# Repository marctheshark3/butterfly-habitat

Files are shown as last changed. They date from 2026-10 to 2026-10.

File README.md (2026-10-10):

# Butterfly habitat

A roughly 200 mm enclosure with a washable floor, drop-in walls, an external
sliding mesh door, and a removable mesh roof. PETG; indoor or sheltered use.

**Revision 0.11 is an engineering candidate.** Fabric thickness is provisionally
0.20 mm. Measure your compressed fabric before final release. Geometry and slicing checks pass with the documented wall supports. Physical fit,
mesh retention, and 50 door cycles remain untested. No support-free claim is made.

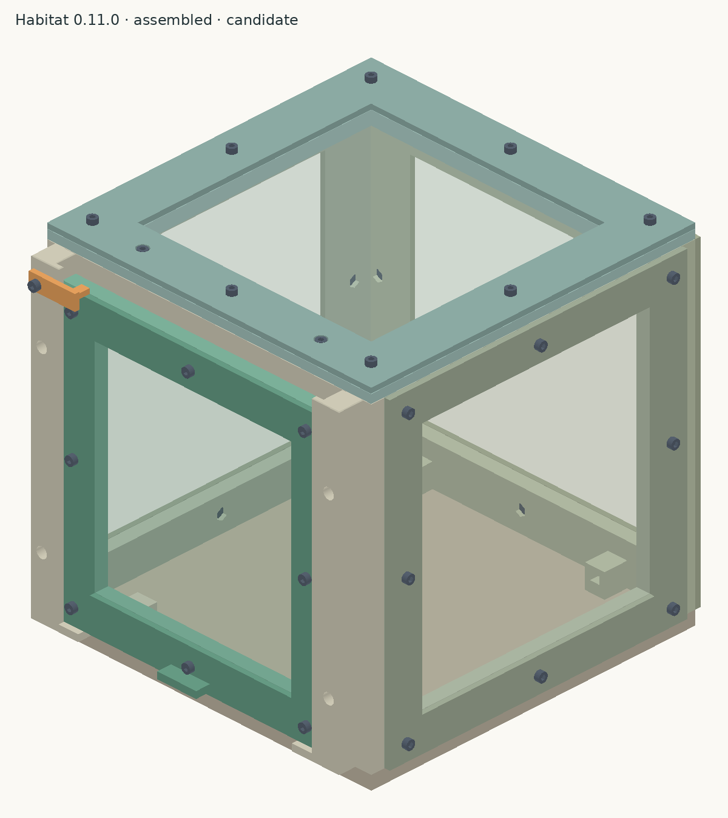
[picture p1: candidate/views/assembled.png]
Assembled habitat


## Start with a small mesh test

Print one of each in PETG:

1. [Mesh-fastener frame coupon](candidate/coupons/mesh-fastener-back.stl).
2. [Matching clamp coupon](candidate/coupons/mesh-fastener-back-clamp.stl).

Import them as **separate objects** in Bambu Studio and keep their supplied
orientations. Test with your actual mesh, M3 × 10 socket-head screws and M3
nyloc nuts. Check nut fit, full engagement through the nylon locking section,
recessed screw tips and firm fabric retention without cracking the clamp.

If that passes, print the [door](candidate/stl/habitat-door.stl) and
[door clamp](candidate/stl/habitat-door-clamp.stl). This tests a complete mesh
border using eight screws and eight nuts, and can become the finished door.
Then test the [rail and corner coupons](candidate/coupons/) before printing the
large panels. The full door-cycle test also needs the front frame, both rails
and keeper. The mesh-fastener coupon prints were reported successful. Mesh was not yet
available for the test; fabric retention, assembled thickness and full hardware
engagement remain unverified.

## P1S print setup

| Setting | Candidate configuration |
| --- | --- |
| Printer / nozzle | Bambu Lab P1S / 0.4 mm |
| Material | PETG; current slices use Generic PETG |
| Build plate | Textured PEI |
| Layer height | 0.20 mm |
| Walls / infill | 4 walls / 20% |
| Brim | 5 mm outer brim |
| Supports | Build-plate-only normal supports on front, back, left and right |
| Orientation | Already applied to STLs; keep it when importing |

Match the slicer’s filament and plate selections to what is actually installed.
The 15 production parts need multiple plates. The existing
[sliced projects](candidate/slicing/) document the candidate settings; inspect
your arranged plate and slice preview before sending a job to the printer.
See the [print specification](docs/PRINT_SPEC.yaml) for part-by-part orientation.

## Color plan

The local inspector previews four filament colors. Screen colors are approximate.

| Color | Parts |
| --- | --- |
| Medium blue | Base, front, back, left, right, roof |
| Matte pink | Back/side/roof clamps and both rails |
| Orange | Door and door clamp |
| Red | Rotating keeper / latch |

These are separate printed parts, so the scheme does not require color changes
within a part. The static reference images below retain the earlier neutral
palette. The inspector palette is defined in `inspector/colors.json`.

The manufacturing baseline remains PETG. If using matte PLA instead, select
its matching filament profile and repeat the fit tests with that material.

### PLA prints while waiting for mesh

The builder selected PLA for the current spools. The
[PLA starter pack](candidate/print-first/README.md) contains prepared P1S projects
for the blue corner-fit coupons, then the actual blue base, blue front and red
keeper. Start with the corner fit; the base is the first full-size print.
These use Generic PLA until a spool-specific profile is selected. The original
`candidate/slicing/` projects remain PETG. Mesh-dependent parts and physical
release checks remain pending.

## Selected mesh candidate

[uxcell 150-micron nylon mesh, 39 × 39 inches](https://www.amazon.com/dp/B09VC3K6C2)
is the selected candidate. One sheet is sufficient for the five panel cutouts.
The 150-micron rating describes the openings, **not the fabric thickness**.
Measure its compressed thickness and test retention with the coupons before
finalizing the mesh-dependent parts. No measured thickness or mesh-fit result
has been recorded yet. The current CAD still assumes 0.20 mm.

For use with monarch eggs and hatchlings, fine mesh alone is insufficient:
door and wall gaps also need checking before the enclosure is used.

## Assembly at a glance

### Built-in part IDs for future prints

The separate [labeled print set](candidate/labeled/README.md) has recessed IDs modeled
into all 15 parts. The existing Bambu projects and unmarked candidate files
remain the current build's print set. There is no need to reprint existing
pieces just for a label; use the [ID key](docs/ASSEMBLY.md#part-id-key) and
[paper labels](candidate/templates/part-labels.svg) to identify them.

| Assembly | IDs |
| --- | --- |
| Base | A1 |
| Front, left rail, right rail, keeper | B1, B2, B3, B4 |
| Back frame and clamp | C1 + C2 |
| Left frame and clamp | D1 + D2 |
| Right frame and clamp | E1 + E2 |
| Door frame and clamp | F1 + F2 |
| Roof frame and clamp | G1 + G2 |

Letters identify assemblies; matching frame/clamp pairs use `1` and `2`.
Left and right are viewed from outside the front doorway. The written guide,
inspector booklet and paper labels use the same IDs.

The marks are 0.4 mm deep with 0.8 mm strokes. Their locations retain at least
1.6 mm of backing and keep the original envelopes and print orientations.
CAD checks cover the labeled solids and interfaces; physical label legibility
and fit remain untested. The [variant manifest](candidate/labeled/assembly/manifest.json)
records each label location and both source hashes. This is still the 0.11.0
engineering candidate, with the same unmeasured mesh assumption.

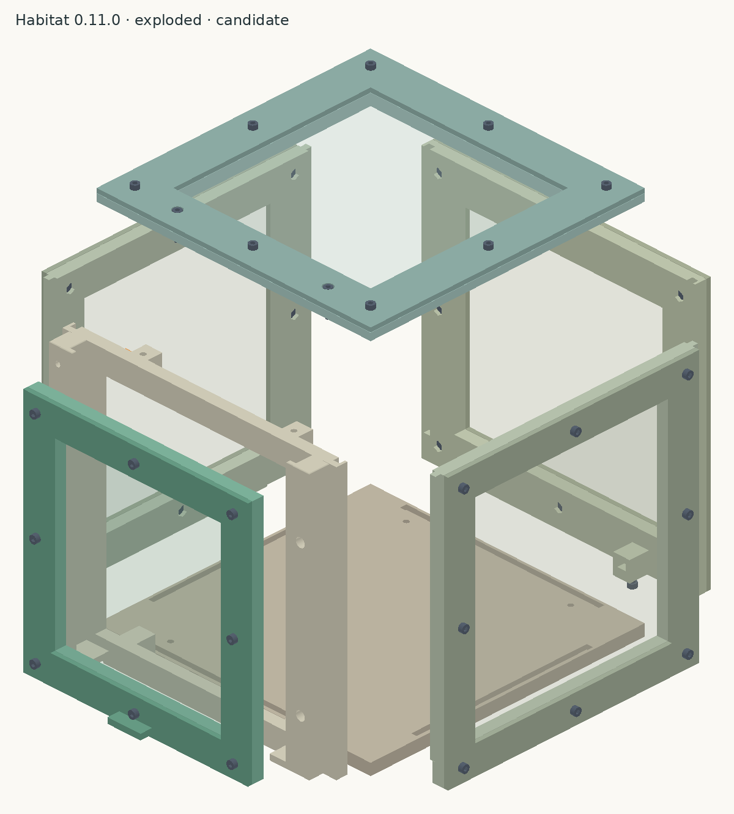
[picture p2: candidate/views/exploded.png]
Exploded CAD reference showing the habitat parts


*Exploded reference view. Offsets show the parts; they are not installation paths.*

1. Clamp mesh to the back, left, right, door and roof frames on the bench.
2. Preload the remaining nuts in the front, back and left rail.
3. Attach the two rails and rotating keeper to the front frame.
4. Seat front and back in the base; secure with four screws from underneath.
5. Lower the side panels into the open wall joints and base grooves.
6. Slide the door down the outside tracks and check the keeper.
7. Seat the roof and install its two separate retention screws from above.
8. Check the fabric, hardware and joints; complete 50 door cycles.

The [illustrated assembly guide](docs/ASSEMBLY.md) gives the hardware counts,
nut directions and checks for each step. Cut mesh using the
[1:1 templates](candidate/templates/) and identify parts with the
[paper labels](candidate/templates/part-labels.svg).

| Hardware | Quantity |
| --- | ---: |
| Stainless M3 × 10 socket-head screw | 45 |
| Stainless M3 × 16 socket-head screw | 6 |
| M3 nyloc nut, 5.5 mm flats × 4 mm overall height | 51 |

Use a 2.5 mm hex driver. The five mesh rings each use eight short screws.
The remaining five short screws attach the rails and keeper. Four long screws
retain the base and two retain the roof. See the [hardware list](candidate/hardware.csv).

### Door and roof access

| Door lifts out with the roof installed | Roof lifts off as one assembly |
| --- | --- |
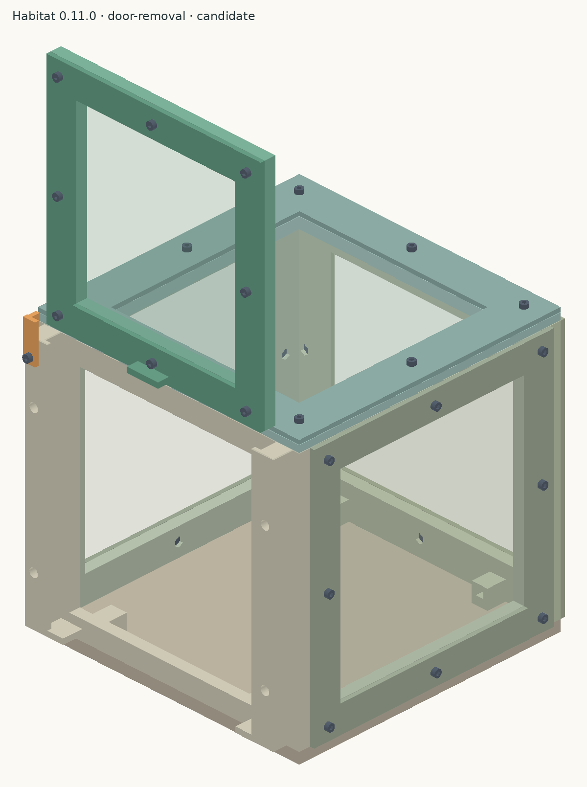
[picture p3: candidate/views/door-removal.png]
Door removal CAD view
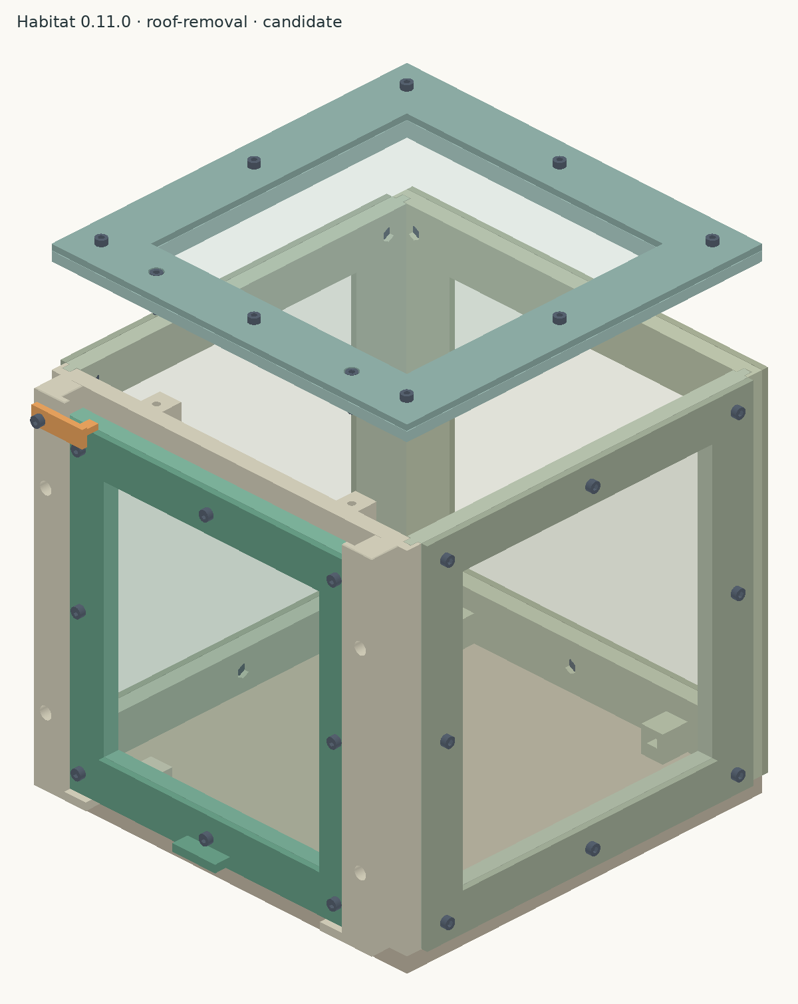
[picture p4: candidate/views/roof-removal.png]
Roof removal CAD view
|  |  |

Swing the keeper clear before lifting the door; allow about 190 mm upward
travel. Remove only the roof’s **two long retention screws** to lift it off.
Its eight mesh screws stay assembled. Keep the walls upright while the roof is off.

## Files

- [Candidate STLs](candidate/stl/) — 15 printed parts, one of each file.
- [STEP parts](candidate/step/) and [complete assembly](candidate/assembly/habitat-assembly.step).
- [Assembly guide](docs/ASSEMBLY.md), [hardware list](candidate/hardware.csv), and [mesh templates](candidate/templates/).
- [Fit coupons](candidate/coupons/) — start here before a complete panel or habitat.
- [Print specification](docs/PRINT_SPEC.yaml) and [validation evidence](candidate/validation.json).
- [Sliced projects](candidate/slicing/) — inspection evidence; review before printing.

Old STLs, snap coupons, source and tests are under `archive/`. Do not mix
revisions. Historical planning notes and camera sketches describe earlier work.

## Local CAD inspector

From the repository root:

```sh
python3 -m http.server 8118 --bind 127.0.0.1 --directory inspector
```

Open [localhost:8118](http://127.0.0.1:8118/). The inspector contains all
122 components: 15 prints, five mesh sheets, 51 screws and 51 nuts.
Drag to orbit, scroll to zoom, click parts to inspect, or use the translucent,
exploded and section views.

The **Instructions** button generates a printable 12-step booklet inside the
inspector, with CAD illustrations, hardware counts and assembly directions.
It shows the five mesh subassemblies separately before the enclosure steps.
The header also links to the written guide.

To refresh the viewer after changing CAD, export its model with FreeCAD and
regenerate the instructions:

```sh
APPIMAGE_EXTRACT_AND_RUN=1 VibeCADCmd scripts/label-parts.py
APPIMAGE_EXTRACT_AND_RUN=1 VibeCADCmd scripts/export-inspector.py
python3 scripts/labels.py
python3 scripts/assembly-guide.py
```

Edit `scripts/assembly-guide.py` to update the shared sequence used by the
Markdown guide, browser guide and inspector booklet.
Edit `src/part_ids.py` for the shared ID map and engraving locations. The label
exporter writes `candidate/labeled/` and does not replace the original print
set. Re-slice the labeled geometry before printing; existing unmarked G-code
cannot acquire labels from a guide update.

## Build and check

The generator needs FreeCAD's Python modules (`FreeCAD`, `Part`, `MeshPart`).
On this workstation VibeCADCmd provides them. It does not set `__main__` when
loading a script, so use the entry point:

```sh
APPIMAGE_EXTRACT_AND_RUN=1 VibeCADCmd scripts/cad-entry.py
APPIMAGE_EXTRACT_AND_RUN=1 HABITAT_ACTION=export VibeCADCmd scripts/cad-entry.py
```

The first command checks in memory. It cannot overwrite STL or STEP files.
The second checks and exports the complete candidate set, manifest, hardware
list, cutting templates, coupons and inspection views. Direct module imports
also have no export side effects. The entry point returns nonzero on validation
failure. Require `geometry_pass: true` and a fresh manifest matching the source hash.

Set `HABITAT_MESH_MM` to your measured compressed thickness and
`HABITAT_MESH_MEASURED=1` only after measuring it. The supported stack range is
0.05–0.40 mm. A thicker material requires a fastening redesign.

```sh
python3 scripts/slice.py --profiles /path/to/BambuStudio/resources/profiles/BBL
python3 scripts/labels.py
python3 -m unittest discover -s tests
# Optional PNG inspection views; needs numpy and Pillow:
python3 scripts/render-views.py
```

To re-slice one part, add `--part habitat-base`. The results for the other parts
are retained. New slices run in a clean temporary directory, so an old project
cannot be mistaken for a successful new slice. Source, profile and project
hashes are recorded with each new result.

For PLA, choose a separate output directory to keep the PETG evidence intact:

```sh
python3 scripts/slice.py --profiles /path/to/BambuStudio/resources/profiles/BBL \
  --filament 'Generic PLA' --output candidate/slicing-pla --part habitat-base
```

An output directory cannot mix different printer/process/filament profiles.
Use a fresh directory when changing those settings. Keep the starter projects'
color assignments when preparing new PLA plates.

## Repository checks

These checks use Python 3.10+ and do not require FreeCAD, Bambu Studio or a
printer. The installer downloads a checksum-pinned Gitleaks release into the
ignored `.local/bin/` directory on Linux or macOS:

```sh
python3 scripts/install-gitleaks.py
python3 -m unittest discover -s tests -v
python3 scripts/package-starter.py --check
python3 scripts/check-secrets.py --history
```

The [GitHub Actions workflow](.github/workflows/checks.yml) runs the same checks
on pushes and pull requests with read-only permissions. It checks exported CAD
evidence and meshes, slicer failure handling, PLA project settings, source
hashes, ZIP contents, and secret detection inside current, staged and historical
print archives. It does not substitute for FreeCAD regeneration or physical
fit tests. Secret handling rules are in [AGENTS.md](AGENTS.md).

To rebuild the PLA download ZIP after an approved project or guide update, run
`python3 scripts/package-starter.py`. It validates the projects first and creates
a repeatable archive containing only the listed files. `--check` verifies the
existing ZIP and loose STL copies without modifying them.

## Validation status

Geometry checks cover all 7,381 assembly pairs, fastener alignment, intended
contacts, door/roof motion and installation access. The 15 production parts
have sliced successfully using the documented P1S PETG settings.

Fabric thickness is still an **unmeasured 0.20 mm assumption**. Coupon fit,
full-panel mesh retention and the 50-cycle door test remain pending. This is
an engineering candidate, not a fit-verified release.
[Verification and release](docs/VERIFICATION.md) describes the checks,
limitations and evidence needed for release.

MIT. See [LICENSE](LICENSE).

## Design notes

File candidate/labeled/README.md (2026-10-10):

# Labeled parts for future prints

Separate engraved-ID variant of the 0.11.0 engineering candidate. The original unmarked STL files, starter pack and current Bambu project are unchanged. Existing parts do not need reprinting for identification.

Each model has a 0.4 mm recessed ID with 0.8 mm strokes. All print orientations and outer dimensions are preserved. Matching frame/clamp pairs share a letter. Left and right are viewed from outside the front doorway.

[Assembly instructions and ID key](../../docs/ASSEMBLY.md#part-id-key) · [Actual STL label close-ups](label-details.png) · [Paper labels](templates/part-labels.svg)

The prepared projects use **Bambu PLA Matte**, a P1S with a 0.4 mm nozzle, Textured PEI, 0.20 mm layers, four walls, 20% infill and a 5 mm outer brim. Front/back/left/right frames have normal build-plate supports. Load the matching color before printing.

| ID | Part | Color | Model | Prepared project |
| --- | --- | --- | --- | --- |
| A1 | base | Blue | [STL](stl/habitat-base.stl) | [Bambu 3MF](slicing-PLA-Matte/habitat-base/sliced.3mf) |
| B1 | front frame | Blue | [STL](stl/habitat-front.stl) | [Bambu 3MF](slicing-PLA-Matte/habitat-front/sliced.3mf) |
| B2 | left rail | Pink | [STL](stl/habitat-rail-left.stl) | [Bambu 3MF](slicing-PLA-Matte/habitat-rail-left/sliced.3mf) |
| B3 | right rail | Pink | [STL](stl/habitat-rail-right.stl) | [Bambu 3MF](slicing-PLA-Matte/habitat-rail-right/sliced.3mf) |
| B4 | keeper / latch | Red | [STL](stl/habitat-keeper.stl) | [Bambu 3MF](slicing-PLA-Matte/habitat-keeper/sliced.3mf) |
| C1 | back frame | Blue | [STL](stl/habitat-back.stl) | [Bambu 3MF](slicing-PLA-Matte/habitat-back/sliced.3mf) |
| C2 | back clamp | Pink | [STL](stl/habitat-back-clamp.stl) | [Bambu 3MF](slicing-PLA-Matte/habitat-back-clamp/sliced.3mf) |
| D1 | left frame | Blue | [STL](stl/habitat-left.stl) | [Bambu 3MF](slicing-PLA-Matte/habitat-left/sliced.3mf) |
| D2 | left clamp | Pink | [STL](stl/habitat-left-clamp.stl) | [Bambu 3MF](slicing-PLA-Matte/habitat-left-clamp/sliced.3mf) |
| E1 | right frame | Blue | [STL](stl/habitat-right.stl) | [Bambu 3MF](slicing-PLA-Matte/habitat-right/sliced.3mf) |
| E2 | right clamp | Pink | [STL](stl/habitat-right-clamp.stl) | [Bambu 3MF](slicing-PLA-Matte/habitat-right-clamp/sliced.3mf) |
| F1 | door frame | Orange | [STL](stl/habitat-door.stl) | [Bambu 3MF](slicing-PLA-Matte/habitat-door/sliced.3mf) |
| F2 | door clamp | Orange | [STL](stl/habitat-door-clamp.stl) | [Bambu 3MF](slicing-PLA-Matte/habitat-door-clamp/sliced.3mf) |
| G1 | roof frame | Blue | [STL](stl/habitat-roof.stl) | [Bambu 3MF](slicing-PLA-Matte/habitat-roof/sliced.3mf) |
| G2 | roof clamp | Pink | [STL](stl/habitat-roof-clamp.stl) | [Bambu 3MF](slicing-PLA-Matte/habitat-roof-clamp/sliced.3mf) |

CAD and slice checks are recorded in [validation.json](validation.json), [the source manifest](assembly/manifest.json) and [slice results](slicing-PLA-Matte/results.json). Motion uses the original, larger part envelopes; the engravings only remove material. Physical fit and printed label legibility remain unverified. Compressed mesh thickness is still the unmeasured 0.20 mm assumption.

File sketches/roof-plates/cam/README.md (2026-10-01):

## Variant: camera roof

### Design stance
The corner is a pod sized to the board. The lens hole stays undrawn until a center exists.

### Key choices
- Pod outer 25.8 by 22.6 mm from the datasheet envelope, 0.4 mm clearance per side, 2.0 mm wall. Clearance and wall are assumed.
- USB slot leaves through the side, not the top.
- Mesh seals to the pod wall.
- Look-down is the sentence already in PRINT_SPEC. It is not a measured aim.

### Trade-offs
- Strong at: replacing the shelf with a real bay, and refusing a fake lens.
- Weak at: cannot be milled until `cam_lens_dx_mm` and `cam_lens_dy_mm` are recorded.

### Best for
A later plate, printed only after the board is measured.

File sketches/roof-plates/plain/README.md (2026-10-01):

## Variant: plain roof

### Design stance
The photo corner is a bug, so the plate is a full mesh frame and nothing else.

### Key choices
- Layout: 200 mm square, 12 mm border, 176 mm window, clamp is a closed ring.
- The 48 by 40 mm shelf and the 8 mm hole are gone.
- Roof still lifts off. That is the hatch.

### Trade-offs
- Strong at: closing the corner, giving the caterpillars mesh there, matching a no-camera build.
- Weak at: no place to put the XIAO without a new plate.

### Best for
The build in hand if the camera stays off.

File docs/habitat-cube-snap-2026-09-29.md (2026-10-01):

> Historical reference. Superseded for printing and assembly by [revision 0.11](../README.md).

# Cube snap coupon

Mesh screws stay mesh screws. The snap coupon is parked. Do not print another pair. Both printed pairs opened a gap after the click. The tighter one was only harder to start.

The drop-in is now in the cube CAD. Spec 0.9.0. Four screws, front and back, into solid corner pads. Not a print. Not fit-tested.

The 0.30 pair was tougher to start and still wiggled. The 0.40 pair started easier and wiggled the same way. Side clearance was not the wiggle. The hook was sitting 3 mm past the lip, so the plates could pull apart that far after they clicked.

- `stl/habitat-snap-tongue-coupon.stl`
- `stl/habitat-snap-pocket-coupon.stl`

The plates are 8 mm, not 6. A 6 mm plate cannot keep a 1.6 mm floor, a 0.8 mm hook, and a 1.6 mm roof. The wall gate failed the 6 mm pocket at a 1.25 mm floor. Do not copy this stack onto a 6 mm frame. The cube mill, later, thickens the pocket locally or turns the hook into the border plane.

Push the tongue into the open end of the pocket. Latched, the tongue is straight. The hook sits in the relief. The lip blocks a straight pull.

## If the click is wrong

Two numbers changed because the last reprint proved the side gap was the wrong knob. Do not reprint the cube.

- Still opens a gap once in: `snap_pocket_depth_mm` to 0.3. Do not tighten the side gap.
- Arm stays bent when the plates are together: `snap_pocket_depth_mm` to 0.8. Do not deepen the hook.
- Will not start: `snap_clearance_per_side_mm` to 0.45. One change.
- Straight pull opens it: `snap_return_angle_deg` to 60.
- Thumb cannot open it: `snap_return_angle_deg` to 40. Do not go to 90.
- Crack at the root after ten cycles: the tongue was printed in the orientation that worked. Do not thicken it on the first crack.

## Screws, later

Not this reprint. The eight M3 holes stay the mesh pinch. They do not join the cube. The four base holes inset 10 mm come out into air. Do not use them.

When the rattle is gone, the cube gets 4 screws, one at each bottom corner, wall into base. The roof stays snaps only, so it still lifts off. If a vertical seam still rattles, 4 more, one mid-height per corner. Ceiling is 8 cube screws. Not eight per frame.

Source stays `assumed` until that rattle is gone. `fit.required` stays false. That block is the door's 2 mm slop.

## Leave alone

Plate A. Door lips. Drain slots. The eight M3 pinch holes. Side length. Lens hole.

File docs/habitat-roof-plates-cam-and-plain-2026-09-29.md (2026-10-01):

> Historical reference. Superseded for printing and assembly by [revision 0.11](../README.md).

# Habitat roof plates, plain and camera, 2026-09-29

Point a session at this file for the roof only. The hinge and the floor slits are a different brief.

[This roof-plate brief](habitat-roof-plates-cam-and-plain-2026-09-29.md)

Sibling, do not merge them into one cut:

[Front hinge and floor brief](habitat-front-hinge-floor-slits-2026-09-29.md)

Drawing, both plates:

[Roof-plate drawing](../sketches/roof-plates/index.html)

For the current local inspector, see the [README](../README.md#local-cad-inspector).

Not a print approval. Pick is Plate A. The live roof is the full mesh frame. Do not send it to the printer from this brief.

## What the photo was

The near corner of the roof was a 48 by 40 mm shelf, 4 mm tall, on the 6 mm plate. An 8 mm hole sat in that shelf. The blue clamp was cut away around it. The tan sheet stopped short of it. That was `build_top` and `build_clamp_roof`. Plate A removes it.

That hole was `cable_hole_diameter_mm`, 8.0, source assumed. It was not a lens. The official DXF has no lens circle. `cam_offsets_ready` stays false. `docs/XIAO_SENSE_DATUM.md` is the record.

The spec used to say the pod is a roof-corner pocket and the lens looks down. Plate A retires that sentence. Plate B stays a drawing until a lens center exists.

## Plate A, no camera

Full 200 mm frame. Border 12 mm. Window 176 by 176 mm. Clamp is a full ring, not a notch. Mesh covers the photo corner. No shelf. No 8 mm hole. Roof still lifts off. That lift is still the hatch.

This is the fix for the shot. It also gives the caterpillars mesh in that corner.

Screw dots on the drawing are M3 clearance, 3.6 mm. They are not a joint into the walls. Do not treat the sketch pattern as a fastener.

## Plate B, camera

Same cube. One corner becomes a pod sized to the board, not a 48 by 40 shelf.

- Board 21.0 by 17.8 by 15.0 mm. Datasheet. Already in the spec.
- Clearance 0.4 mm per side. Assumed. Pocket 21.8 by 18.6 mm.
- Wall 2.0 mm. Assumed. Above the 1.6 mm minimum wall.
- Pod outer 25.8 by 22.6 mm. It eats the 12 mm border and a bite of the window.
- USB slot 9.0 by 3.5 mm on the short edge, out the side face of the cube. Not a hole in the top.
- Mesh seals to the pod wall. No open step like the photo.
- Lens looks down. That is the existing spec sentence, not a measured aim.
- Lens hole is not drawn. Center is unknown. Do not cut a 6 mm aperture until a caliper or a marked board supplies `cam_lens_dx_mm` and `cam_lens_dy_mm`.

The red dash on the drawing is a warning, not a hole.

## Decision

Write one line here before any roof cut.

Pick: Plate A. Camera stays off. The 48 by 40 shelf is not an option.

- Recommend if the cam stays off. Plate A.
- Plate B only after a lens center exists. Until then Plate B is a drawing.
- Do not keep the 48 by 40 shelf as a third option. That is the bug.

## Leave alone in this cut

Front hinge. Floor slots. Side length. A printed grille. A lens hole with no datum.

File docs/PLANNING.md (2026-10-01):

> Historical reference. Superseded for printing and assembly by [revision 0.11](../README.md).

# Planning notes

For the next session. Not a print approval. Camera pod stays off.

## What is true now

The cube is a stack of plates. The front butts the floor, the two sides, and the roof. It does not snap, and nothing screws it on. The four holes in the front corners exit into empty air. The floor corner holes miss the walls the same way.

The door drops into three lips and lifts out the open top. Its screws match the door clamp only. They pinch a bought sheet. They do not enter the front.

The side walls are 188 mm. They stop at the inside face of the back. The earlier overlap, about 7040 mm3, is gone. The back stays a full 200 mm frame. The side clamp is its own part, `habitat-clamp-side`, printed twice. Project gate passed at revision 0.3.0.

The roof lifts off. That is the hatch. It is also not screwed to the cube.

## Still open: how the cube stays together

Do not pretend the current holes are a joint. The next session picks one fastener and cuts only that.

Options, in the order I would try them:

1. Screws through the front border into the front edge of each side, and the same at the back. The sides are 6 mm thick, so this is an end-grain screw into a short edge. It needs a real hole in that edge, not the mesh-clamp holes that already exist.
2. A tab on the front that drops into a slot in the floor, plus the roof sitting on it so it cannot lift. Still not a snap. Still needs a wind check.
3. Leave it a butt and glue it. Fine for a one-off. Bad if the girls need to take it apart.

The roof has the same problem, and it has to stay removable. A fastener there has to hold in the wind and still lift off with a chrysalis attached to the mesh.

## Pupation

"Patch" here means pupate. A monarch ready to pupate crawls up, lays a silk pad, hangs in a J from its rear prolegs, then hooks the cremaster into that pad as the skin sheds. In mesh pop-up cages they do this on the roof mesh. Do not move them once the pad is started. If the chrysalis is on the lid, the lid moves with it.

Sources: Monarch Butterfly Garden on mesh-roof pupation, Tyrant Farms on the J-hang and the mesh ceiling, Monarch Joint Venture on the silk pad and cremaster.

The roof sheet in the inspector is that surface. It is a 0.3 mm stand-in, not a measured cloth. Organza and no-see-um may be slicker than the mesh in those cage photos. That is the open question, not a new printed part.

Do not design a stick holder. A stick can be dropped in later if the sheet will not hold silk. A rough strip on the roof underside is the other low-parts option, and only if a real sheet fails. Not this session.

## Letting them out

The hatch is the whole roof, not a door in the roof. Lift the roof, the sheet, and the roof clamp as one stack. A chrysalis on that sheet comes with the roof. That is how you move one. It is also how you can tear a silk pad if you rush it.

Daily access is the front door. Release is after the adult has emerged and dried, then the roof comes off or the door opens. Do not pull a wet butterfly. Do not add a second hatch until the roof fastener is decided. The exploded view already lifts that stack so the motion is visible.

## Leave alone

Camera pod. Printed grille. Hardware cloth. A stick CAD feature. Screws that do not enter another part.

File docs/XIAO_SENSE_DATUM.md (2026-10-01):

> Historical reference. Superseded for printing and assembly by [revision 0.11](../README.md).

# XIAO ESP32-S3 Sense lens datum

The lens circle is not identifiable in the official Seeed DXF. Offsets were not recorded. `cam_offsets_ready` stays false. The pod was not cut.

Source: https://files.seeedstudio.com/wiki/SeeedStudio-XIAO-ESP32S3/res/XIAO_ESP32S3_ExpBoard_v1.0_top.dxf

File: `XIAO_ESP32S3_ExpBoard_v1.0_top.dxf`, 160474 bytes, SHA-256 `4039bf565f6bece5209c60877c804c1f0bd2507173ec9905d5eb8c7ec79949cc`, AutoCAD R11/R12 (`AC1009`).

Provenance: datasheet drawing. Not measured on our board.

## Findings

- `cam_lens_dx_mm`: not recorded. No lens circle.
- `cam_lens_dy_mm`: not recorded. No lens circle.
- USB-C edge: not identifiable. No USB label, and no USB-C shell on either the short 17.8 mm edge or the long 21 mm edge.

The datasheet envelope is 21.0 x 17.8 mm. This top drawing does not contain that rectangle, so there is no Sense board center to subtract from.

## Entities used

No `CIRCLE`, `ARC`, `TEXT`, or `MTEXT` entities. Entity counts: `POLYLINE` 565, `VERTEX` 1134, `INSERT` 8, plus block definitions. The strings USB, lens, CAM, and Sense do not occur.

Header extents do not match the Sense envelope and do not match the placed geometry:

- `$EXTMIN` 10=-3.9200 20=7.3080
- `$EXTMAX` 10=18.1737 20=43.5115
- span 22.0937 x 36.2035 mm

The only board-like outline is layer `20`, a rounded rectangle drawn as open polylines. Centerline:

- left: (-0.635, 14.478) to (-0.635, 26.035)
- right: (17.145, 26.035) to (17.145, 14.478)
- top: (1.27, 27.94) to (15.24, 27.94)
- bottom: (15.24, 12.573) to (1.27, 12.573)
- four corner arcs, bulge 0.4142 (90 deg), radius 1.905 mm, for example (1.27, 27.94) bulge 0.4142 to (-0.635, 26.035)

Centerline extents: 17.780 mm by 15.367 mm. That is not 21.0 x 17.8 mm.

Closed circles in this R12 file are two `bulge=1` semicircles, not `CIRCLE` entities. The largest are pad-scale, not a lens:

- layer 21, center (0.955, 20.955), diameter 0.4064 mm, vertices (0.955, 20.7518) bulge 1 and (0.955, 21.1582) bulge 1
- layer 25, center (0.0, 22.479), diameter 0.400 mm, vertices (0.0, 22.279) bulge 1 and (0.0, 22.679) bulge 1
- layer 25, center (7.747, 19.177), diameter 0.300 mm
- layer 25, center (7.747, 20.701), diameter 0.300 mm

`INSERT` of block `ROUNDP` (local vertices (0, -0.25) bulge 1 and (0, 0.25) bulge 1, scale 1.27, diameter 0.635 mm):

- (-0.635, 25.019), rotation 270
- (17.145, 25.019), rotation 90

Those are round pads on the 17.780 mm edges of the layer-20 outline. They are not a camera lens. No closed circle in the file has a lens-scale diameter.

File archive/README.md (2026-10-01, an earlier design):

# Superseded experiments

Revision 0.10 source, source-text tests, and exports are retained for comparison.
They are not production parts and do not satisfy the current assembly checks.
The archived generator has import-time export side effects. Do not execute it.
Snap coupons and camera sketches are excluded from the current print list.

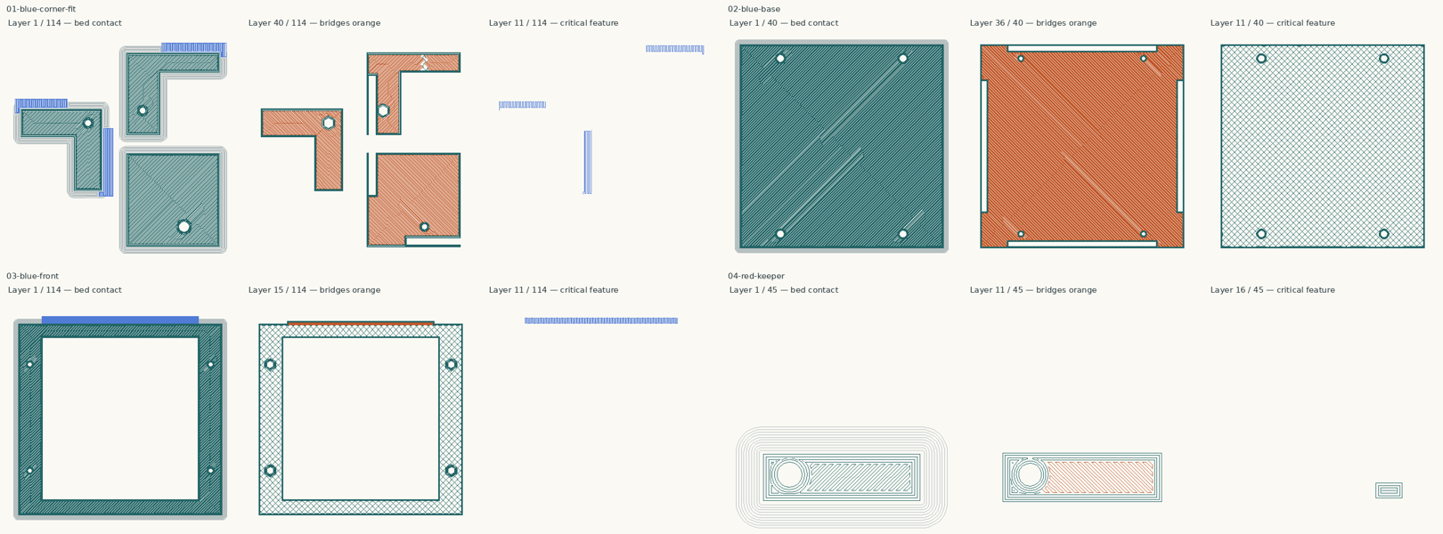
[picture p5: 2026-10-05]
candidate/print-first/layer-overview.png

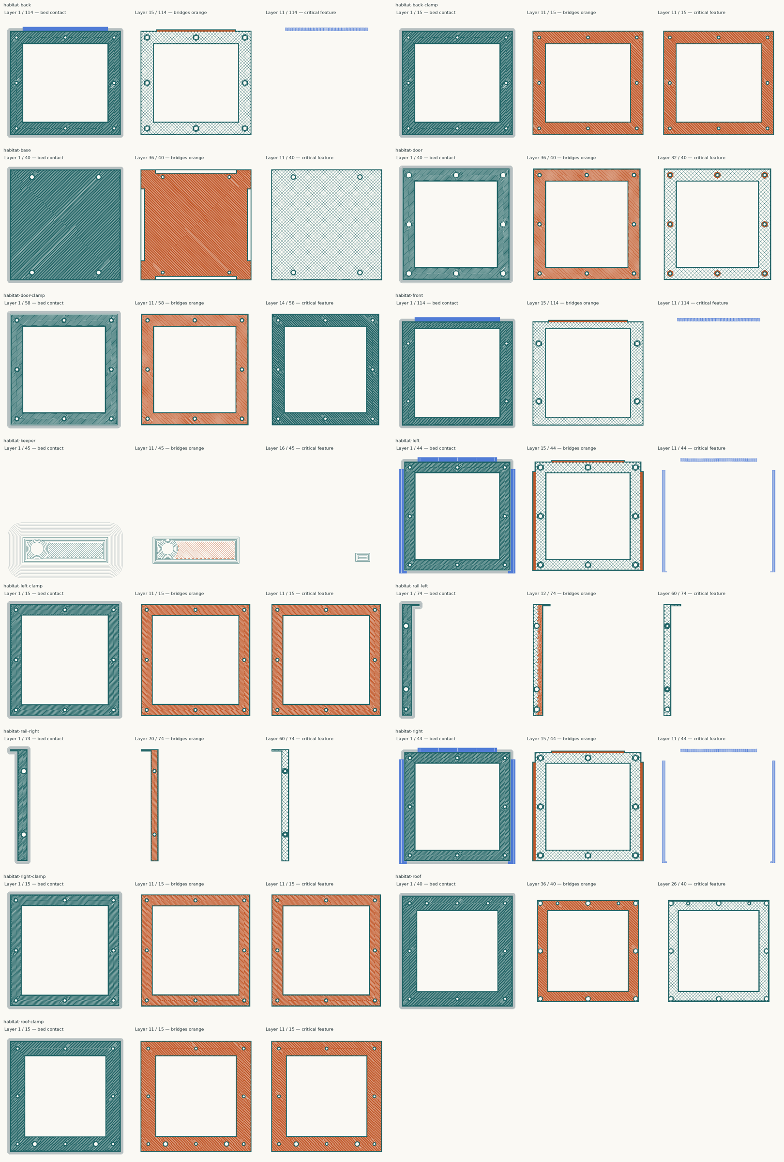
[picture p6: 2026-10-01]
candidate/slicing/layer-overview.png

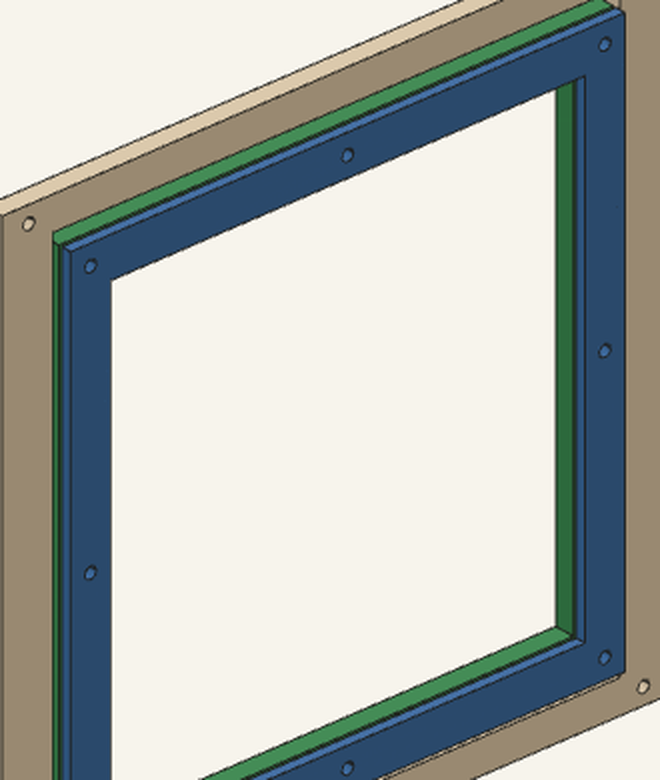
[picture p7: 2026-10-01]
docs/images/door-screws.png

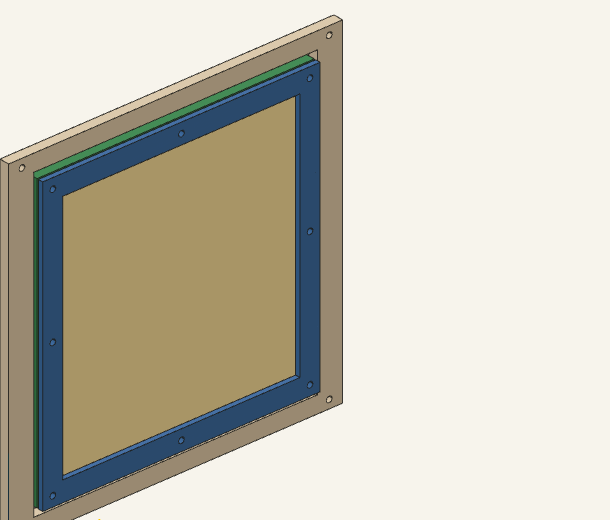
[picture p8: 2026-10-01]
docs/images/door-seat.png

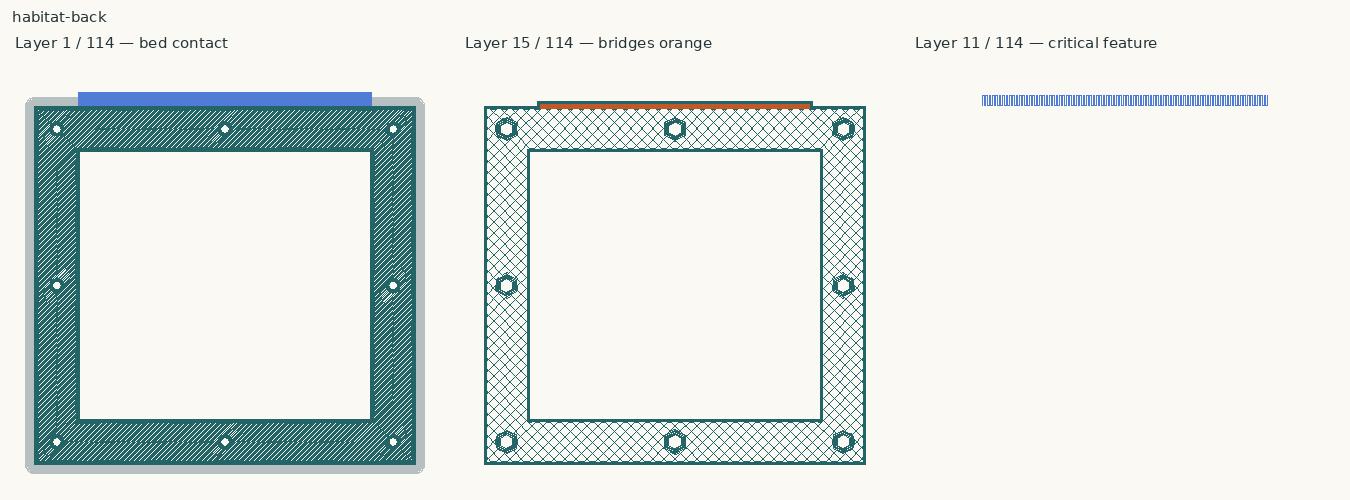
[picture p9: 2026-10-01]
candidate/slicing/habitat-back/layers.png

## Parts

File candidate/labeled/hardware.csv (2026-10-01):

item | quantity | length_mm
M3 A2 socket-head screw | 45 | 10
M3 A2 socket-head screw | 6 | 16
M3 A2 nyloc nut NN3SS | 51 | 4

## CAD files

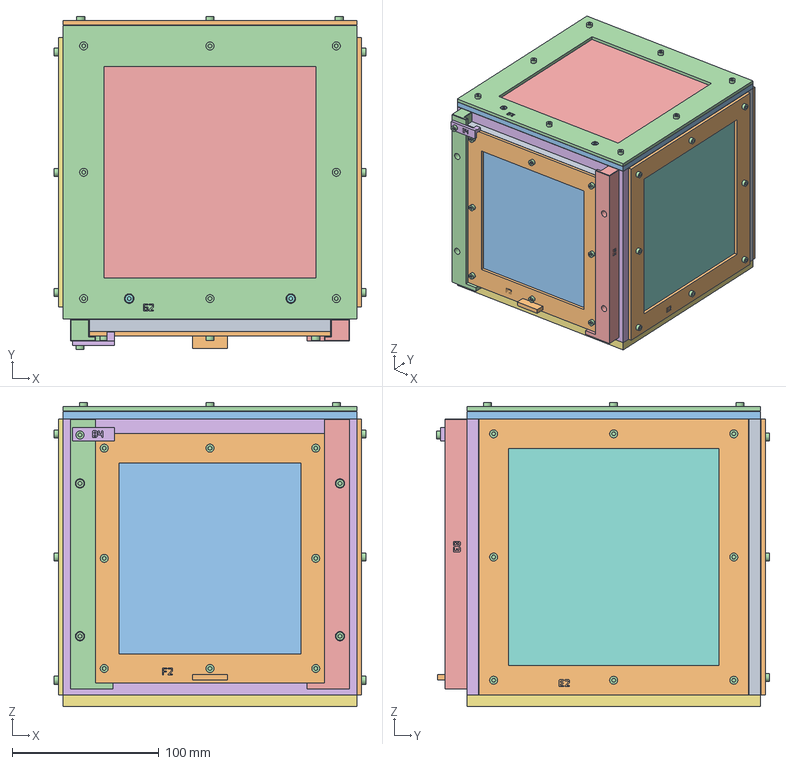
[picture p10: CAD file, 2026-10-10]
candidate/labeled/assembly/habitat-assembly.step
212.4 x 227.0 x 207.2 mm

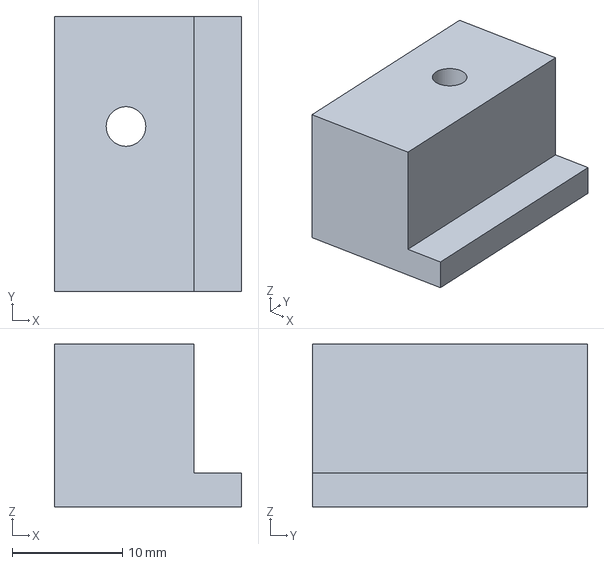
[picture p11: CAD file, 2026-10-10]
candidate/labeled/coupons/rail-rail-left.step
17.0 x 25.0 x 14.8 mm

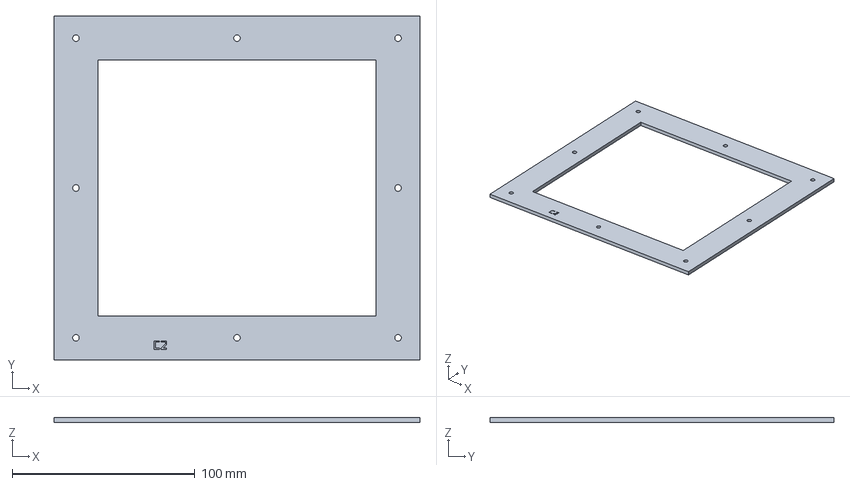
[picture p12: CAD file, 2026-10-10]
candidate/labeled/slicing-PLA-Matte/habitat-back-clamp/sliced.3mf
200.0 x 187.8 x 3.00 mm

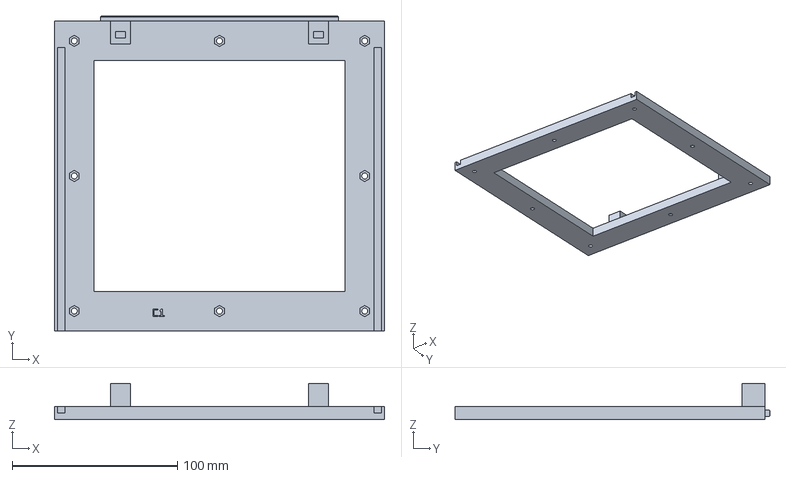
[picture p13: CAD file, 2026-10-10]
candidate/labeled/slicing-PLA-Matte/habitat-back/sliced.3mf
200.0 x 190.8 x 22.0 mm

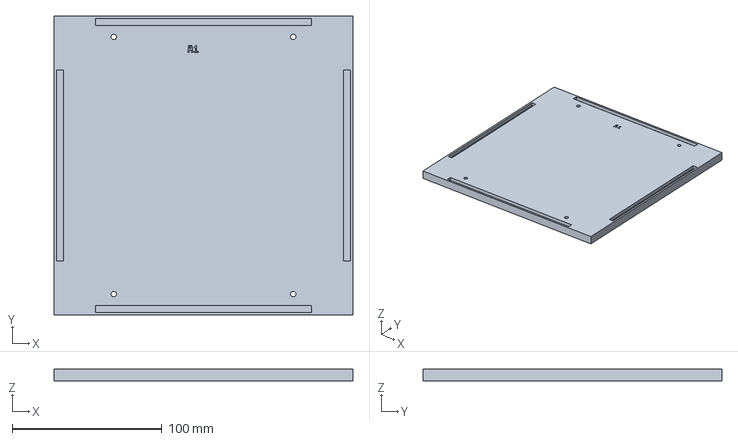
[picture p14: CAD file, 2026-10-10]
candidate/labeled/slicing-PLA-Matte/habitat-base/sliced.3mf
200.0 x 200.0 x 8.00 mm

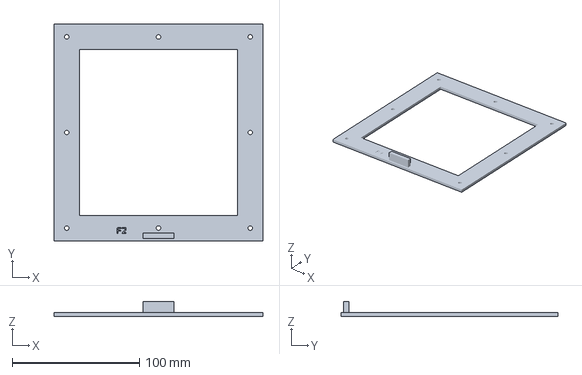
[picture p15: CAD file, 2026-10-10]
candidate/labeled/slicing-PLA-Matte/habitat-door-clamp/sliced.3mf
164.0 x 170.0 x 11.5 mm

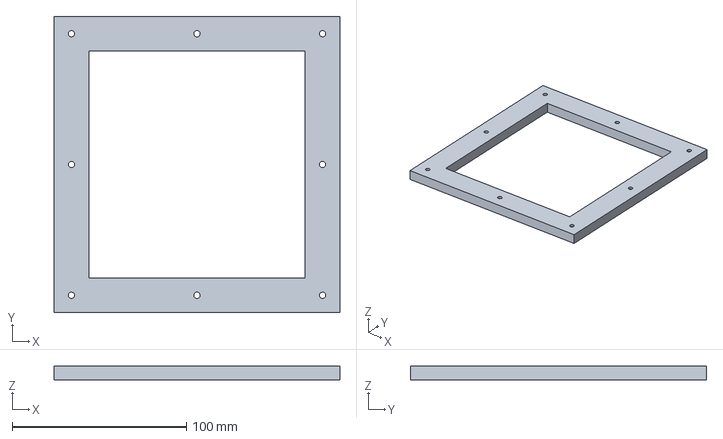
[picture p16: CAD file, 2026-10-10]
candidate/labeled/slicing-PLA-Matte/habitat-door/sliced.3mf
164.0 x 170.0 x 8.00 mm

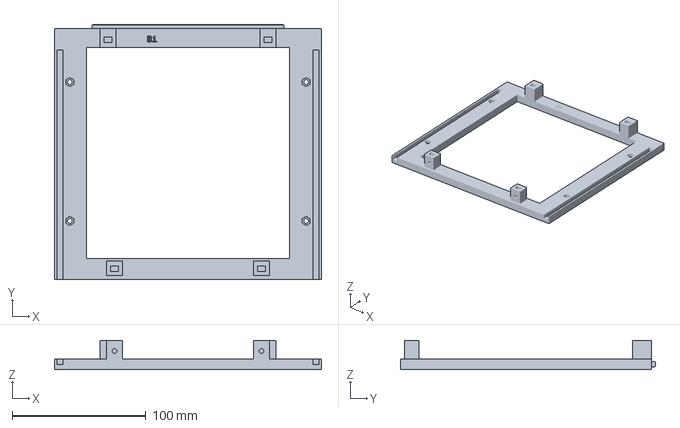
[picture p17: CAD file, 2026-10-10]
candidate/labeled/slicing-PLA-Matte/habitat-front/sliced.3mf
200.0 x 190.8 x 22.0 mm

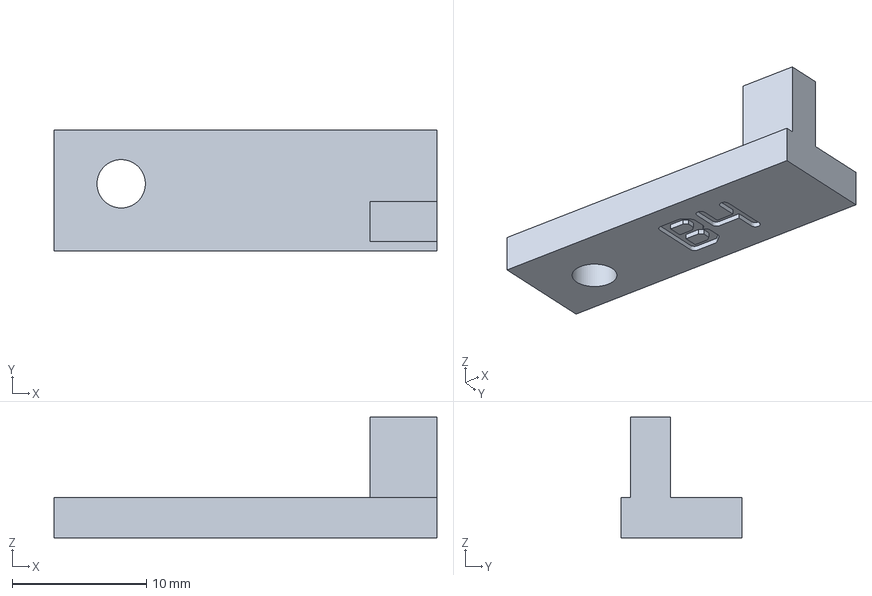
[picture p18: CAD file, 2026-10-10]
candidate/labeled/slicing-PLA-Matte/habitat-keeper/sliced.3mf
28.5 x 9.00 x 9.00 mm

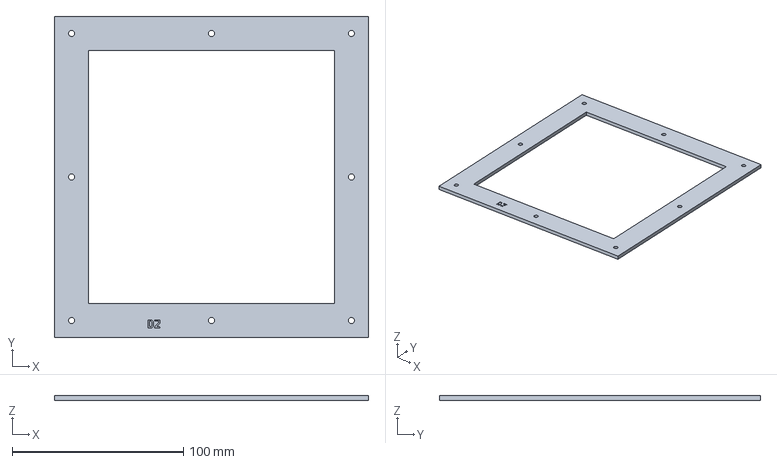
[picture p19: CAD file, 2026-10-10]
candidate/labeled/slicing-PLA-Matte/habitat-left-clamp/sliced.3mf
183.5 x 187.8 x 3.00 mm

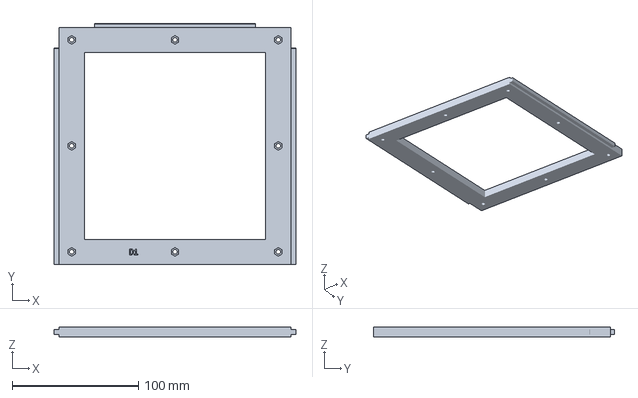
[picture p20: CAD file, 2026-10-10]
candidate/labeled/slicing-PLA-Matte/habitat-left/sliced.3mf
191.5 x 190.8 x 8.00 mm

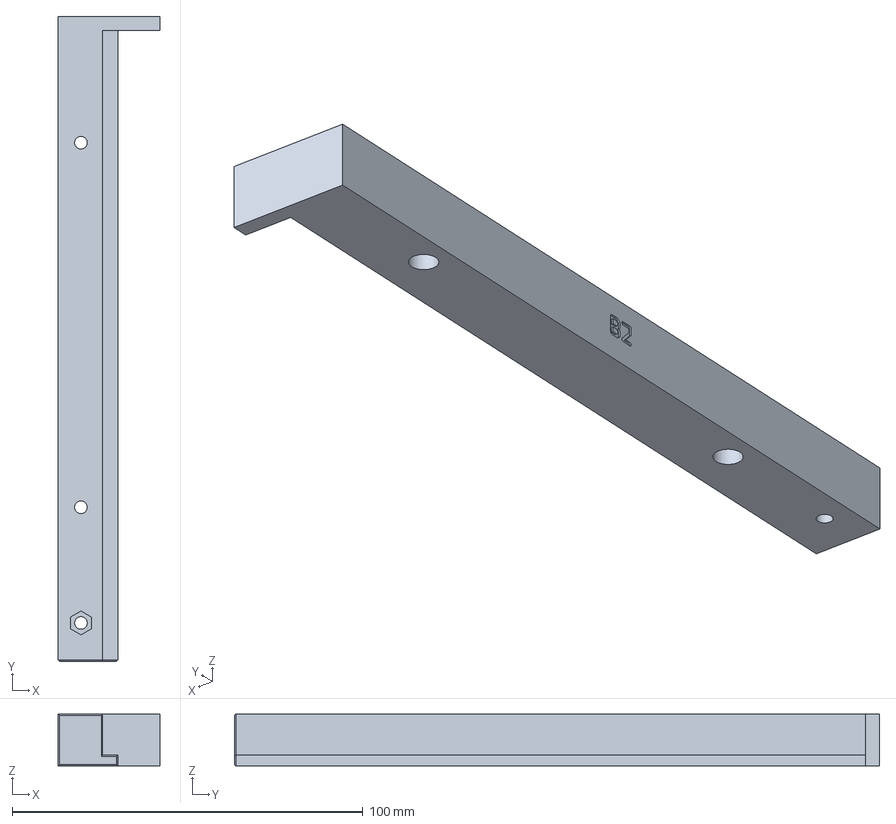
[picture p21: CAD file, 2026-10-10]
candidate/labeled/slicing-PLA-Matte/habitat-rail-left/sliced.3mf
29.0 x 184.0 x 14.8 mm

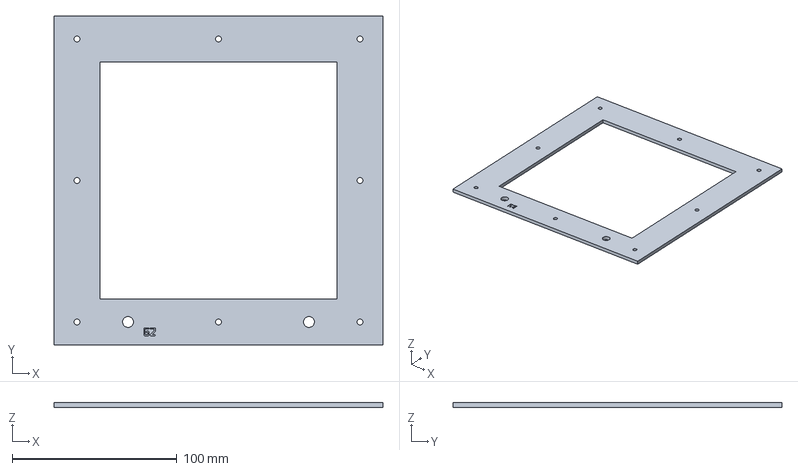
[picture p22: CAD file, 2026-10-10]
candidate/labeled/slicing-PLA-Matte/habitat-roof-clamp/sliced.3mf
200.0 x 200.0 x 3.00 mm

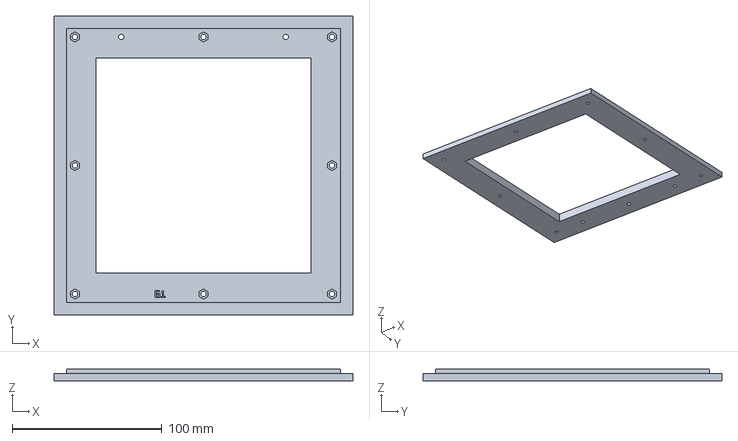
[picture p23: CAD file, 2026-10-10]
candidate/labeled/slicing-PLA-Matte/habitat-roof/sliced.3mf
200.0 x 200.0 x 8.00 mm

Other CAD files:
candidate/labeled/slicing-PLA-Matte/habitat-rail-right/sliced.3mf
candidate/labeled/slicing-PLA-Matte/habitat-right-clamp/sliced.3mf
candidate/labeled/slicing-PLA-Matte/habitat-right/sliced.3mf
candidate/labeled/step/habitat-right.step
archive/v0.10/step/habitat-back.step
archive/v0.10/step/habitat-base.step
archive/v0.10/step/habitat-clamp-door.step
archive/v0.10/step/habitat-clamp-roof.step
archive/v0.10/step/habitat-clamp-side.step
archive/v0.10/step/habitat-clamp-wall.step
archive/v0.10/step/habitat-door-frame.step
archive/v0.10/step/habitat-front.step
archive/v0.10/step/habitat-left.step
archive/v0.10/step/habitat-right.step
archive/v0.10/step/habitat-snap-pocket-coupon.step
archive/v0.10/step/habitat-snap-tongue-coupon.step
archive/v0.10/step/habitat-top.step
archive/v0.10/stl/habitat-back.stl
archive/v0.10/stl/habitat-base.stl
archive/v0.10/stl/habitat-clamp-door.stl
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

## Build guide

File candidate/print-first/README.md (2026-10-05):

# First prints while the mesh is on the way

Prepared for the builder's **PLA** on a **Bambu Lab P1S, 0.4 mm nozzle**.
These revision 0.11 candidate projects use **Generic PLA**, because the spool
brand/line has not been specified. The original projects in `candidate/slicing/`
still use PETG; use the PLA projects in this folder for these prints.

## Print order and files

| Order | Bambu Studio project | Color | Estimate | What it is |
| --- | --- | --- | --- | --- |
| 1 | [Corner fit](01-blue-corner-fit/01-blue-corner-fit.3mf) | Blue | 1 h 24 min / 42 g | Three test coupons: base, front and left wall |
| 2 | [Base](02-blue-base/02-blue-base.3mf) | Blue | 3 h 42 min / 156 g | The actual finished floor, 200 × 200 mm |
| 3 | [Front](03-blue-front/03-blue-front.3mf) | Blue | 2 h 16 min / 76 g | The actual finished front doorway frame |
| 4 | [Keeper](04-red-keeper/04-red-keeper.3mf) | Red | 11 min / 1 g | The actual finished rotating latch; set aside for the rails |

Estimates come from Bambu Studio 2.4.0.70 with the included settings. Each
project has one plate and one filament color. The first three objects are
**test pieces**, not parts of the finished enclosure. The base, front and
keeper projects each contain one full production part.

The base is the first full-size print after the corner test passes. Its shape,
the front frame and the keeper's printed shape do not depend on compressed
mesh thickness in the current CAD. Their physical fit still needs checking.

The builder reported a successful corner-coupon print. A detailed mechanical
fit result has not yet been recorded; this does not verify mesh retention or
complete enclosure assembly.

## Check the three corner pieces

1. Print them in the same blue PLA intended for the finished body. Remove the
   brim and the supports from the front/left locating tongues.
2. Seat the front coupon's bottom tongue in the matching base groove. With
   one M3 nyloc nut in the inward-facing boss slot, fasten it using one
   M3 × 16 socket-head screw from underneath. The nut's nylon end faces up.
3. Slide the left coupon down into the front coupon's vertical slot and its
   matching base groove. The wall shoulders should seat without forcing,
   drilling or sanding. Check that the screw head is recessed and the screw
   engages the nylon section of the nut.
4. If the joints bind or the parts crack, adjust the fit before printing the
   large pieces. A successful dry corner test does not establish mesh retention
   or door operation.

## Bambu setup

Open a `.3mf` as a **project** so Bambu loads its printer, filament and process
settings. The oriented STLs are included in the ZIP for manual import too;
import them as separate objects and keep their supplied orientations.

| Setting | Saved value |
| --- | --- |
| Printer / nozzle | Bambu Lab P1S / 0.4 mm |
| Filament | Generic PLA |
| Plate | Textured PEI |
| Nozzle / bed | 220 °C / 55 °C, from the Generic PLA profile |
| Layers | 0.20 mm |
| Walls / infill | 4 / 20% |
| Brim | 5 mm outer brim |
| Supports | Normal automatic, build plate only, on front/left coupons and full front |
| No supports | Base coupon, full base and keeper |
| Scale | 100%; original print orientation preserved |

If your spool has a matching manufacturer profile (for example Bambu PLA
Matte), select it and re-slice before printing. Match the project's single
filament to the loaded spool or AMS slot. No AMS or within-part color changes
are needed. Review the slice, leave bed leveling enabled, and start the job
when the correct spool and clean plate are installed.

Bambu's PLA profile displays a warm-enclosure warning with this heated plate:
follow its ventilation guidance for the P1S.

## Color plan for the complete habitat

| Color | Parts |
| --- | --- |
| Medium blue `#388DC7` | Base, front, back, left, right, roof |
| Pink `#F0A4BA` | Back/side/roof clamps and both rails |
| Orange `#F68C38` | Door and door clamp |
| Red `#DD4945` | Keeper / latch |

Use the pink spool's matte finish if available; screen colors are approximate.
Each part is a single color. These assignments match `inspector/colors.json`.

## When the mesh arrives

Measure its **compressed thickness**, then use the already-printed mesh-fastener
coupons to check retention and hardware engagement. The CAD currently assumes
0.20 mm, which is not a measurement. The mesh opening rating is not its thickness.
If those coupons used another material, repeat them in the intended PLA.

Wait on the full back/side/roof mesh panels, door, clamps and rails until the
mesh stack is checked. Mesh thickness changes panel nut-pocket depths and rail
geometry. Then proceed with the complete door and sliding tests before printing
the remaining set. PLA fit, mesh retention and the 50-cycle door test remain
unverified; this pack does not change the project's release status.

## File checks

All four projects were sliced with Bambu Studio. The archives, embedded G-code
checksums, PLA settings, colors, object counts, support settings and plate bounds
were checked. `manifest.json` records source STL hashes and estimates.
`layer-overview.png` shows first layers and selected bridge/feature layers from
the actual G-code. CAD comparisons at 0.05, 0.20 and 0.40 mm compressed mesh
confirmed identical printed geometry for the base, front and keeper; see
`mesh-independence.json`. The corner project was also opened and sliced in the
Bambu Studio desktop app, showing Generic PLA, 42.30 g and 1 h 24 min.
CLI logs retain the existing display/thumbnail warnings;
the exported projects contain G-code.

Settings were applied using Bambu's documented
[command-line workflow](https://github.com/bambulab/BambuStudio/wiki/Command-Line-Usage).

From the repository root, verify these projects and their download with
`python3 scripts/package-starter.py --check`. After an approved asset or guide
update, `python3 scripts/package-starter.py` rebuilds the ZIP from the manifest
and matching source STLs. The checks do not send anything to a printer.

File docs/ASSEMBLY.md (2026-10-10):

# Assembly — revision 0.11

Revision 0.11 engineering candidate. Digital geometry and slicing checks pass. Physical assembly, fabric retention and 50 door cycles still need testing. The model assumes 0.20 mm compressed mesh; measure your fabric and regenerate before final printing.

## Before assembly

- Print and test the fit coupons first, then a complete door panel and representative corner. Remove supports and brim before checking fit. The four wall panels require the documented build-plate supports.

- Identify all 15 printed parts using the part-ID key below. Use the current 0.11 fit geometry; the original unmarked parts and the engraved-ID variant share the same mating geometry.

- Lay out 45 stainless M3 × 10 socket-head screws, six M3 × 16 socket-head screws, 51 M3 nyloc nuts (5.5 mm flats, 4 mm overall height), and a 2.5 mm hex driver. Screw length is measured beneath the head.

- Cut five mesh sheets using the matching 1:1 templates: back 198 × 185.75 mm; left and right each 181.5 × 185.75 mm; door 162 × 168 mm; roof 198 × 198 mm. Check the printed scale. Make the eight screw openings in each sheet; only the roof also needs two larger retention-access openings.

[Mesh cutting templates and part labels](../candidate/templates/) · [Hardware list](../candidate/hardware.csv)

## Part-ID key

Each letter identifies one assembly; matching frame and clamp IDs end in 1 and 2. Left and right are viewed from outside the front doorway. The future-print labeled variant has small recessed IDs. Existing unmarked 0.11 parts can be identified with this key and the paper labels; they do not need reprinting just for identification. The labeled variant preserves the original fit geometry and print orientations. Its physical fit and label legibility still need a printed check.

| ID | Part | Engraved label location |
| --- | --- | --- |
| A1 | base | inside floor, near the back edge |
| B1 | front frame | inside face of the lower border |
| B2 | left rail | outer side, halfway up |
| B3 | right rail | outer side, halfway up |
| B4 | keeper / latch | outer face of the latch arm |
| C1 | back frame | inside face of the upper border |
| C2 | back clamp | outward face of the lower border |
| D1 | left frame | inside face of the upper border |
| D2 | left clamp | outward face of the lower border |
| E1 | right frame | inside face of the upper border |
| E2 | right clamp | outward face of the lower border |
| F1 | door frame | rear face of the lower border |
| F2 | door clamp | outward face, beside the finger grip |
| G1 | roof frame | underside border, clear of the locating grooves |
| G2 | roof clamp | upper face of the border |

[Future-print labeled STLs](../candidate/labeled/stl/) · [Label geometry and validation](../candidate/labeled/assembly/manifest.json)

## Build order

Mesh panels → preload remaining nuts → rails and keeper → base and front/back → sides → door → roof → checks.

## 1. Prepare the five mesh panels

**Hardware:** 40 M3 × 10 screws + 40 M3 nyloc nuts

1. Pair each frame with its matching clamp: C1 back frame with C2 back clamp; D1 left frame with D2 left clamp; E1 right frame with E2 right clamp; F1 door frame with F2 door clamp; G1 roof frame with G2 roof clamp. B1 front frame is the open doorway and has no mesh clamp.
2. On each frame, put eight nuts in the hex pockets opposite the clamp face. Point each nut’s nylon end away from the clamp. Hold loose nuts with temporary tape until the screws engage.
3. Lay the matching mesh sheet on the frame, place the clamp over it, and insert eight 10 mm screws from the clamp side. Start all eight before tightening gradually around the border. Remove temporary tape.
4. Check that the fabric is held around the entire opening, the clamp stays flat and screw tips remain recessed. Set the five completed panels aside.

CAD reference view; separated parts show orientation, not an installation sequence.

## 2. Load the remaining nuts while the parts are accessible

**Hardware:** 11 M3 nyloc nuts

1. B1 front frame: insert two nuts in the lower inward-facing boss slots for the base, two in the upper inward-facing boss slots for the roof, and four in the inside-face hex pockets for the rails. Total: eight nuts.
2. C1 back frame: insert two nuts in the lower inward-facing boss slots for the base.
3. B2 left rail: insert one nut in the inside-face pocket behind the keeper pivot before mounting the rail.
4. Base nuts have nylon ends upward; roof nuts have nylon ends downward. Rail and keeper nuts have nylon ends toward the inside of the enclosure. Temporarily retain any loose nuts until their screws engage.

## 3. Attach the rails and keeper to the front frame on the bench

**Hardware:** 5 M3 × 10 screws; nuts loaded in step 2

1. Place B1 front frame with its outside face accessible. Put B2 left rail and B3 right rail on the outside, with their stops at the bottom and their open track ends at the top. Left and right are as viewed from outside the front.
2. Insert two 10 mm screws through each rail’s deep counterbores into the front frame nuts. Seat the heads; keep the running channels clear.
3. Attach B4 keeper / latch to the top of B2 left rail using the fifth 10 mm screw. Adjust the pivot so the keeper moves by hand and stays where placed. Swing its arm clear of the door path.

## 4. Fasten the front and back to the base

**Hardware:** 4 M3 × 16 screws; nuts loaded in step 2

1. The grooved face of A1 base goes up; the recessed screw-head pockets go underneath. Place it on two supports so you can reach the underside without turning loose walls over.
2. Seat B1 front frame’s bottom tongue in the front groove, with rails outside and nut bosses inside. Hold it upright and insert two 16 mm screws from below.
3. Seat the completed C1 back frame / C2 back clamp panel in the opposite groove, with its mesh clamp outside. Hold it upright and insert the remaining two 16 mm screws from below.
4. Check that both walls sit fully down and all four heads sit within their underside recesses. Remove temporary nut-retaining tape.

## 5. Slide in the side panels

**Hardware:** No additional hardware

1. Keep the roof off. Hold the completed D1 left frame / D2 left clamp panel with its mesh clamp facing out. Align both vertical edge tongues with the open slots on the inside faces of the front and back.
2. Lower the panel straight down until its bottom tongue seats in the base. Repeat for the completed E1 right frame / E2 right clamp panel.
3. Check that all four wall tops are level. Keep the enclosure upright; the side panels can still lift out until the roof is secured.

## 6. Insert the door and check the keeper

**Hardware:** Completed door panel; no additional hardware

1. With B4 keeper / latch swung clear, hold the completed F1 door frame / F2 door clamp panel above the rail openings. Its clamp and projecting finger grip face outward; the grip is at the bottom.
2. Lower both door edges into the tracks together until the door rests on both bottom stops. Do not force a tight track.
3. Swing the keeper across the top of the closed door so its hook prevents the door lifting. Swing it clear again and check that the door slides freely.

Insert the door and check the keeper

## 7. Attach the complete roof

**Hardware:** 2 M3 × 16 screws; nuts loaded in step 2

1. Place the completed G1 roof frame / G2 roof clamp panel with its locating grooves down and mesh clamp up. Its two larger retention-access holes go toward the front, over the two upper front-frame bosses.
2. Lower it onto all four wall tops. Insert one 16 mm screw through each large access hole into the front-frame nuts. These two screws seat on the roof frame.
3. Leave the eight short mesh screws assembled. To remove the roof later, remove only the two long retention screws and lift the entire roof assembly. Keep the enclosure upright while the roof is off.

Attach the complete roof

## 8. Check the completed enclosure

**Hardware:** Physical acceptance checks

1. Confirm all nuts engage their nylon locking section, screw tips are recessed, the base sits flat and the mesh has no loose border or escape gaps.
2. With the roof installed, swing the keeper clear and raise the door through its full travel. It should lift completely out; allow about 190 mm of upward travel. Reinsert it and close the keeper.
3. Complete and record 50 door cycles without binding or damage. Require hand assembly without drilling or sanding. Record failed fits for correction before calling the design fit verified.

Check the completed enclosure

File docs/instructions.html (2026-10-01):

Assembly order is centroid z, then y, then x, then name. Not an LDraw model. Not print approval.

# Butterfly habitat

Assembly order is centroid z, then y, then x, then name. Not an LDraw model. Not print approval.

1. Step 1 · 1× · habitat-assembly-0
2. Step 2 · 1× · habitat-assembly-3
3. Step 3 · 1× · habitat-assembly-7
4. Step 4 · 2× · habitat-assembly-6, habitat-assembly-8
5. Step 5 · 1× · habitat-assembly-9
6. Step 6 · 1× · habitat-assembly-1
7. Step 7 · 1× · habitat-assembly-2
8. Step 8 · 1× · habitat-assembly-5
9. Step 9 · 1× · habitat-assembly-4
10. Step 10 · 1× · habitat-assembly-10
11. Step 11 · 1× · habitat-assembly-11

1

1×

habitat-assembly-0

2

1×

habitat-assembly-3

3

1×

habitat-assembly-7

4

2×

habitat-assembly-6 ×2

5

1×

habitat-assembly-9

6

1×

habitat-assembly-1

7

1×

habitat-assembly-2

8

1×

habitat-assembly-5

9

1×

habitat-assembly-4

10

1×

habitat-assembly-10

11

1×

habitat-assembly-11

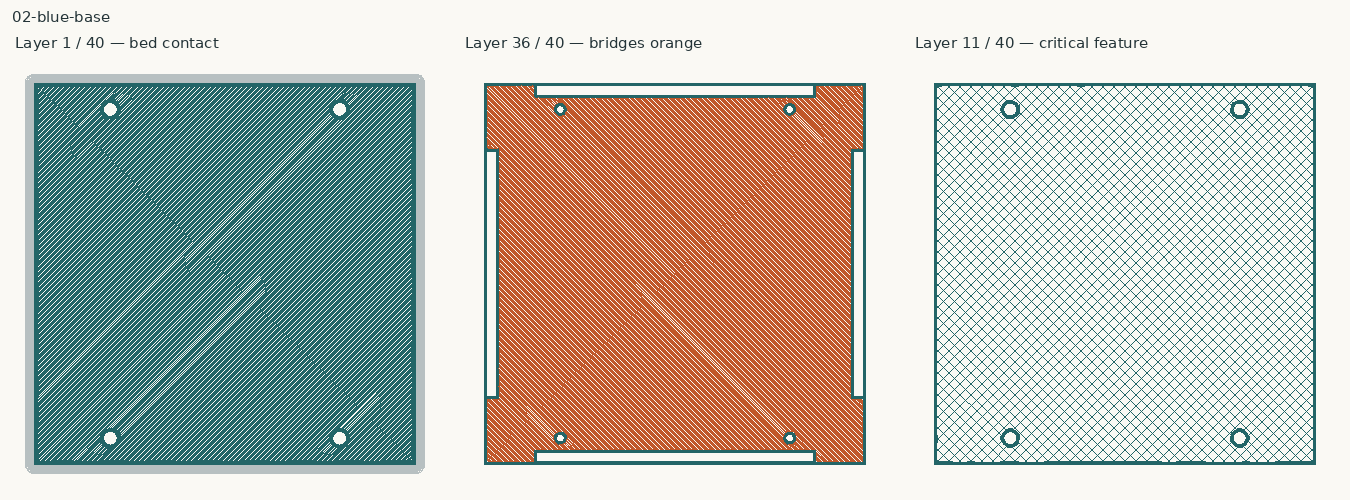
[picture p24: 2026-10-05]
candidate/print-first/02-blue-base/layers.png

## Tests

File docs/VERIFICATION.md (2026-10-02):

# Verification and release

## Current candidate results

- 15 CAD/STL parts pass; independent mesh topology checks pass.
- 7,381 assembled pairs pass at 0.001 mm³; all motion/access checks pass.
- Six standard-library regression tests pass. The FreeCAD regression also rejects
  a deliberately misaligned side clamp and confirms import/build/check do not
  modify STL or STEP files.
- All 15 P1S PETG jobs slice successfully. First-layer, bridge and critical-feature
  previews were inspected. Four walls require the supplied support settings.
- Layer-centre checks found zero disconnected unsupported islands.
- Cut/pocket dimensions, critical webs and visible slicer perimeters were reviewed.
  This is an engineering audit, not a general medial-axis thickness proof.
- Compressed fabric remains an **unmeasured 0.20 mm assumption**. Physical tests
  are pending. Release remains blocked on the fabric measurement; print the full
  set only after the coupon, panel/corner and door-cycle tests pass.

The dated review and its source hash are in
[`candidate/required-review.json`](../candidate/required-review.json).

## Physical test report

The mesh-fastener coupon prints were reported successful by the builder.
No mesh was available during that test. This is a limited print result;
compressed mesh thickness, fabric retention, full hardware engagement and the
complete door/corner checks are still pending. `physical_fit_pass` remains false.

## What is automated

The assembly definition contains 15 printed bodies, five compressed-fabric
sheet envelopes, 51 screws, 51 nuts, all placements, panel hole patterns and
mating relationships. It drives STEP, oriented STLs, inspection views, hardware
counts, cutting templates and coupons.

Every body must be a valid, closed, connected CAD solid. Every tessellated part
must be a closed single-component mesh and fit a 256 mm bed with a 5 mm brim.
Exported STLs are read back and checked again. Independent standard-library
tests check edge incidence, winding, connectedness and signed volume.

All 7,381 instance pairs are checked, including hardware and fabric. There are
no collision exemptions. Intersections larger than **0.001 mm³** fail. Contact
without positive volume is permitted. The nut's thread bore clears the screw's
thread envelope; axial engagement is checked separately. Four millimetres of
nut engagement and 1 mm protrusion beyond the full nut envelope are modeled.

Checks also cover:

- Door removal through 190 mm with the roof and unlocked keeper present.
- The keeper's 90-degree turn: exact hook sweep and a conservative rear-plate
  disc envelope, both checked against the assembly.
- Roof removal through 20 mm, retaining all mesh hardware.
- Vertical wall installation/removal through 200 mm at the stated assembly
  stage. Parts installed later are absent; mesh hardware stays attached.
- Translational screw and nut installation paths through their receiving parts.
- A 5 mm diameter, 40 mm long driver shaft at every screw. Use a long shaft;
  bulky handles or powered-driver bodies are outside this model.
- Actual wall-joint and door running clearances, critical web dimensions,
  and uninterrupted 3 mm fabric-contact bands around each opening.
- First-layer area in each assigned orientation.

The translational sweeps union the starting solid with its extruded boundary
faces. This is a continuous sweep, not a set of discrete door positions.
Inspection drawings use the same shapes but do not substitute for solid checks.

## What still needs evidence

The critical-web checks are not a general minimum-thickness proof over every
point of every curved edge. Thin walls and intentional edge chamfers were reviewed in
the current slice; repeat that review after a geometry or mesh-stack change. Chamfered entry edges intentionally taper below the nominal web.
FDM strength, actual clearance, nyloc insertion force and fabric retention need
physical tests.

`candidate/slicing/` contains one P1S PETG project per printed part, flattened
profiles and source STL hashes. Successful G-code generation alone does not
prove printability. Inspect first layers, bridges, pockets, side tongues, rail
entry chamfers and the keeper hook. Use the 0.4 mm nozzle and 0.2 mm layers.
Check for unsupported islands and missing walls. The current slicing recipe
enables normal build-plate supports on front, back, left and right to support the
locating tongues. The other eleven parts are sliced without supports.
`candidate/layer-check.json` checks each 0.2 mm layer centre for disconnected
unsupported islands; it does not prove that connected cantilevers will print well.
`candidate/slicing/layer-overview.png` shows first layers and selected bridge layers.
[Prusa's printing design guidance](https://help.prusa3d.com/article/modeling-with-3d-printing-in-mind_164135)
explains why orientation and slicer inspection matter.

Some Bambu CLI builds report a missing display while omitting thumbnails even
when G-code is successfully generated. The slice script verifies that the
archive contains G-code and preserves the log. Those messages must not be
mistaken for a completed visual review.

## Release gates

1. Measure compressed fabric and regenerate with `HABITAT_MESH_MM` and
   `HABITAT_MESH_MEASURED=1`.
2. Run full geometry checks and export. `HABITAT_SKIP_MOTION=1` is only for
   debugging; it cannot export or release.
3. Slice all oriented STLs. Inspect every part, including critical layers.
4. Record revision-matched evidence in `candidate/required-review.json`:
   source SHA-256, compressed mesh thickness, named reviewer, observations,
   `slicer_review_pass`, and `wall_thickness_review_pass`.
5. Run `HABITAT_ACTION=release` with the same mesh settings. All geometry is
   regenerated and checked; release artifacts are written together to `release/`.
   They may be called **digitally verified** only after those reviews pass.
6. Print coupons, the complete door mesh panel with its front/rail/keeper test
   fixture, and the representative corner. Require hand
   assembly without drilling/sanding, secure fabric, recessed tips, complete nut
   engagement and 50 door cycles without binding or damage. Record results.
   Set `physical_fit_pass` only after all pass; then release may be called
   **fit verified**.

The default candidate is neither digitally verified nor fit verified. No
physical testing, material measurement or human slicer review is inferred from
a generated file or a passing source-code test.

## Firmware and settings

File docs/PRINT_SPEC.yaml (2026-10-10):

schema_version: 2
part:
  name: butterfly-habitat
  revision: 0.11.0
  status: engineering-candidate
  body_envelope_mm: [200, 200, 201]
  envelope_note: Exterior clamps, heads, rails and finger grip extend beyond body.
  purpose: Bought-mesh enclosure with washable floor and removable door/roof.
manufacturing:
  process: fdm
  printer: bambu-lab-p1s
  build_volume_mm: [256, 256, 256]
  material: PETG
  nozzle_mm: 0.4
  layer_height_mm: 0.2
  walls: 4
  infill_percent: 20
  brim_mm: 5
  bed: textured-PEI
  support_free_verified: false
  support_required_parts: [front, back, left, right]
  support_type: normal-auto-build-plate-only
  support_angle_deg: 45
cad:
  backend: FreeCAD-Part
  source: src/butterfly-habitat.py
  entry_point: scripts/cad-entry.py
  assembly_manifest: candidate/assembly/manifest.json
  validation_report: candidate/validation.json
  import_writes_files: false
  default_action: check
geometry:
  nominal_min_wall_mm: 1.6
  structural_boss_width_mm: 12
  panel_mm: 8
  clamp_mm: 3
  intersection_tolerance_mm3: 0.001
  collision_exemptions: []
  intended_contact: [head-seats, nut-seats, wall-shoulders, door-bottom-stops, fabric-lands]
  edge_tapers: 0.4 mm entry chamfers on locating tongues and rail entries
  thickness_validation: Critical dimensions and slice features reviewed; intentional edge tapers excluded.
fit:
  required: true
  wall_joints:
    clearance_per_side_mm: 0.25
    parameter: WALL_FIT
    coupon: candidate/coupons/corner-base.stl
  door:
    running_face_clearance_mm: 0.30
    parameter: DOOR_FIT
    closed_overlap_mm: 6
    opening_mm: [152, 158]
    carrier_mm: [164, 170]
    removal_travel_mm: 190
    coupon: candidate/coupons/rail-rail-left.stl
  hardware:
    radial_clearance_mm: 0.30
    parameter: HARDWARE_RADIAL_FIT
    hole_diameter_mm: 3.6
    nut_flat_clearance_per_side_mm: 0.20
    nut_parameter: NUT_FIT
    coupon: candidate/coupons/mesh-fastener-back.stl
  evidence: Physical coupons and 50-cycle test pending.
mesh:
  sheets: 5
  screws_per_ring: 8
  compressed_thickness_mm: 0.20
  thickness_measured: false
  accepted_stack_range_mm: [0.05, 0.40]
  continuous_contact_band_mm: 3
  templates: candidate/templates/
hardware:
  material: stainless-A2
  screws:
    head_type: socket-head-DIN912
    diameter_mm: 3
    pitch_mm: 0.5
    head_diameter_mm: 5.5
    head_height_mm: 3
    driver_mm: 2.5
    quantities:
      - {length_mm: 10, quantity: 45, use: '40 mesh + 4 rails + 1 keeper'}
      - {length_mm: 16, quantity: 6, use: '4 base + 2 roof'}
    source: https://belmetric.com/content/A-PDF_Drawings/BSH3X10SS.pdf
  nuts:
    type: M3-nyloc-DIN985
    supplier_part: NN3SS
    quantity: 51
    across_flats_mm: 5.5
    overall_height_including_nylon_mm: 4
    engagement_mm: 4
    tip_beyond_nut_mm: 1
    source: https://belmetric.com/content/A-PDF_Drawings/NN3SS.pdf
  modeled_as: Conservative hardware envelopes with cleared thread bores.
  tool_access_envelope_mm: {diameter: 5, shaft_length: 40}
print:
  stl_directory: candidate/stl/
  quantity_each: 1
  orientations_already_applied_to_stl: true
  parts:
    - {id: base, file: habitat-base.stl, bed_face: underside}
    - {id: front, file: habitat-front.stl, bed_face: exterior, up: inward-bosses}
    - {id: back, file: habitat-back.stl, bed_face: exterior-mesh-land, up: inward-bosses}
    - {id: left, file: habitat-left.stl, bed_face: exterior-mesh-land}
    - {id: right, file: habitat-right.stl, bed_face: exterior-mesh-land}
    - {id: roof, file: habitat-roof.stl, bed_face: exterior-mesh-land, up: grooves}
    - {id: door, file: habitat-door.stl, bed_face: rear}
    - {id: back-clamp, file: habitat-back-clamp.stl, bed_face: mesh-contact-land}
    - {id: left-clamp, file: habitat-left-clamp.stl, bed_face: mesh-contact-land}
    - {id: right-clamp, file: habitat-right-clamp.stl, bed_face: mesh-contact-land}
    - {id: roof-clamp, file: habitat-roof-clamp.stl, bed_face: mesh-contact-land}
    - {id: door-clamp, file: habitat-door-clamp.stl, bed_face: mesh-contact-land, up: finger-grip}
    - {id: rail-left, file: habitat-rail-left.stl, bed_face: broad-retaining-face}
    - {id: rail-right, file: habitat-rail-right.stl, bed_face: broad-retaining-face}
    - {id: keeper, file: habitat-keeper.stl, bed_face: broad-outer-face}
  excluded: [archive, sketches, experimental-snap-coupons]
part_identification:
  variant: engraved-ids-1
  source: src/part_ids.py
  exporter: scripts/label-parts.py
  stl_directory: candidate/labeled/stl/
  preserves_original_print_set: true
  depth_mm: 0.4
  stroke_mm: 0.8
  minimum_backing_checked_mm: 1.6
  id_key: docs/ASSEMBLY.md#part-id-key
  physical_legibility_verified: false
service:
  environment: indoor-or-sheltered
  floor: solid-washable
  drainage: none
  camera: none
validation:
  cad_solids: see-generated-report
  stl_manifold_and_components: see-generated-report
  assembly_pairs_and_motion: see-generated-report
  fastener_and_mesh_paths: see-generated-report
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

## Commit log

2026-09-28 Printable butterfly habitat kit.
    200 mm PETG panel kit with a printed 2 mm grille and M3 clearance holes.
    Photo was a style reference, not a measurement.
    [habitat-back.step, habitat-back.stl, habitat-base.step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]
2026-09-28 Clamp bought mesh between the frames.
    Drop the printed grille. A 2 mm hole does not hold a hatchling.
    [habitat-clamp-door.step, habitat-clamp-door.stl, habitat-clamp-roof.step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]
2026-09-28 Publish the clamp-ring source, not the old grille script.
2026-09-29 cad: declare camera pod parameters
2026-09-29 docs: record XIAO lens datum from the Seeed DXF
2026-09-29 docs: camera stays a ledge, screen is a bought sheet
2026-09-29 docs: roof line is a cable ledge, not a camera
2026-09-29 docs: Lego sheet from the mill STEP
2026-09-29 viewer: seat the door and draw the cloth stand-in
    The sheet is a 0.3 mm viewer solid in the clamp gap. It is not an STL and not a measured fabric.
2026-09-29 docs: front holes do not join the cube
    The corner screws exit into air. The side walls intersect the back.
2026-09-29 fix: sides stop at the back instead of running through it
    Left and right are 188 mm. The side clamp is its own part. The front is still a butt joint.
    [habitat-clamp-side.step, habitat-clamp-side.stl, habitat-left.stl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]
2026-09-29 docs: pick Plate A and retire the roof pod sentence
2026-09-29 fix: roof is a full mesh frame, no shelf
2026-09-29 fix: export Plate A roof frame and closed clamp
    [habitat-clamp-roof.step, habitat-clamp-roof.stl, habitat-top.step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]
2026-09-29 docs: roof drawing and readme match Plate A
2026-09-29 feat: cube snap parameters, mesh screws unchanged
    The eight M3 holes still pinch bought mesh. Snap dimensions are in the
    contract so a coupon can be cut without touching the cube.
    [PRINT_SPEC.yaml]
2026-09-29 feat: snap coupon probe, not milled
    A 14 mm tongue and a lipped pocket mate with the arm straight. The cube
    builders do not call them. Mesh screws are untouched.
2026-09-29 feat: mill snap coupon pair
    Tongue and pocket mate with the arm straight. Cube STLs are untouched.
    The coupon plate is 8 mm because a 6 mm pocket failed the wall gate.
    [habitat-snap-pocket-coupon.step, habitat-snap-pocket-coupon.stl, habitat-snap-tongue-coupon.step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]
2026-09-29 fix: snap coupon clearance is 0.4 mm per side
    0.25 mm was under one nozzle line, and a 0.2 mm STL chord ate the gap.
    Cube STLs are untouched. Fit is still assumed.
    [habitat-snap-pocket-coupon.step, habitat-snap-pocket-coupon.stl, habitat-snap-tongue-coupon.step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]
2026-09-29 fix: snap coupon clearance 0.30 after a loose click
    The 0.40 pair started and latched, then rattled. Hook is unchanged.
    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
    [habitat-snap-pocket-coupon.step, habitat-snap-pocket-coupon.stl, habitat-snap-tongue-coupon.step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]
2026-09-30 fix: hook slack 0.5 mm, clearance back to 0.40
    The 0.30 pair was harder to start and still opened a gap. That gap was
    3 mm of hook travel past the lip, not the side clearance.
    [habitat-snap-pocket-coupon.step, habitat-snap-pocket-coupon.stl, habitat-snap-tongue-coupon.step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]
2026-09-30 feat: drop-in groove is an inspector section, not a print
    Snap stays parked. Cube STLs are not cut.
2026-09-30 Cut drop-in grooves and four corner screws into the cube.
    Walls drop into base grooves and neighbor slots. Roof lip stops the lift. Screws pin the front and back into solid pads, not the mesh holes. Not a print.
    [habitat-back.step, habitat-back.stl, habitat-base.step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]
2026-10-01 spec: seat redesign is 0.10.0, door opening 152 mm
    [PRINT_SPEC.yaml]
2026-10-01 cad: one seat_layout and a screw at x=17
2026-10-01 cad: roof grooves run through the wall-top corners
2026-10-01 cad: joint bosses are 10 mm square around the bore
2026-10-01 cad: back frame is 24 mm and its mesh holes stay at inset 6
2026-10-01 cad: seat probe fails a roof corner hit or a thin screw ligament
    _yaw no longer zeros Z. The foot tongue hangs below 0, and zeroing it lifted the side 4 mm through the roof skin.
2026-10-01 cad: mill the seat redesign, door opening 152 mm
    [habitat-back.step, habitat-back.stl, habitat-base.step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]
2026-10-01 cad: strip FreeCAD trailing spaces from STEP headers
    [habitat-back.step, habitat-base.step, habitat-front.step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]
2026-10-01 Redesign habitat assembly and add illustrated print and assembly guides
    [corner-base.step, corner-base.stl, corner-front.step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]
2026-10-05 Add secure PLA print setup and starter bundle
    - Add staged PLA coupon and habitat print projects with slicing evidence
    - Add reproducible starter packaging, secret scanning, tests, and CI checks
    - Document print workflow and repository safety requirements
    [01-blue-corner-fit.3mf, 02-blue-base.3mf, 03-blue-front.3mf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]
2026-10-10 Add engraved part IDs for future prints
    [corner-base.step, corner-base.stl, corner-front.step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]
